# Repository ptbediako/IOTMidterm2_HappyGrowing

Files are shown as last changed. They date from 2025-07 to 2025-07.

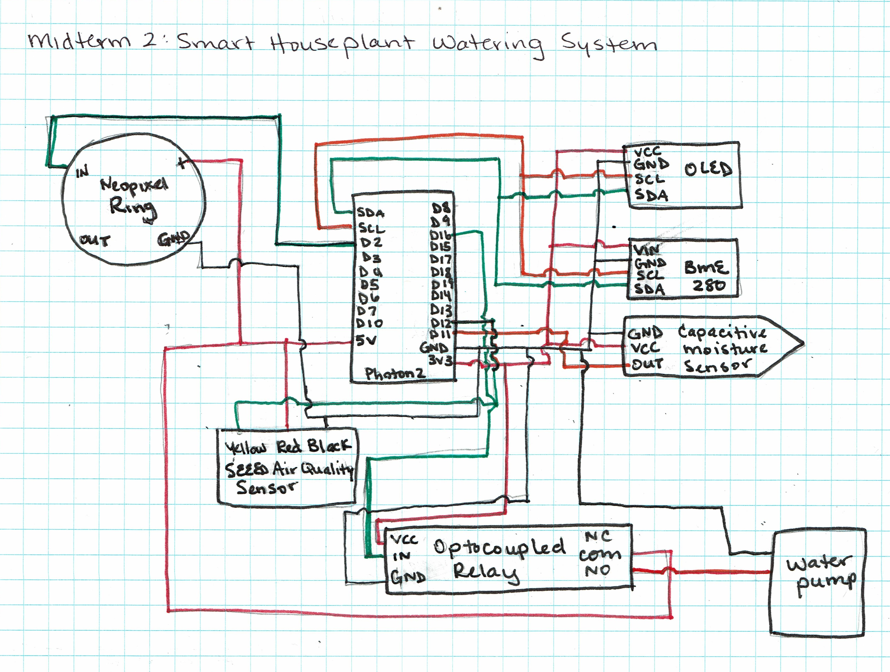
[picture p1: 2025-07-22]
Midterm2 Schematic_20250721cropped.jpg

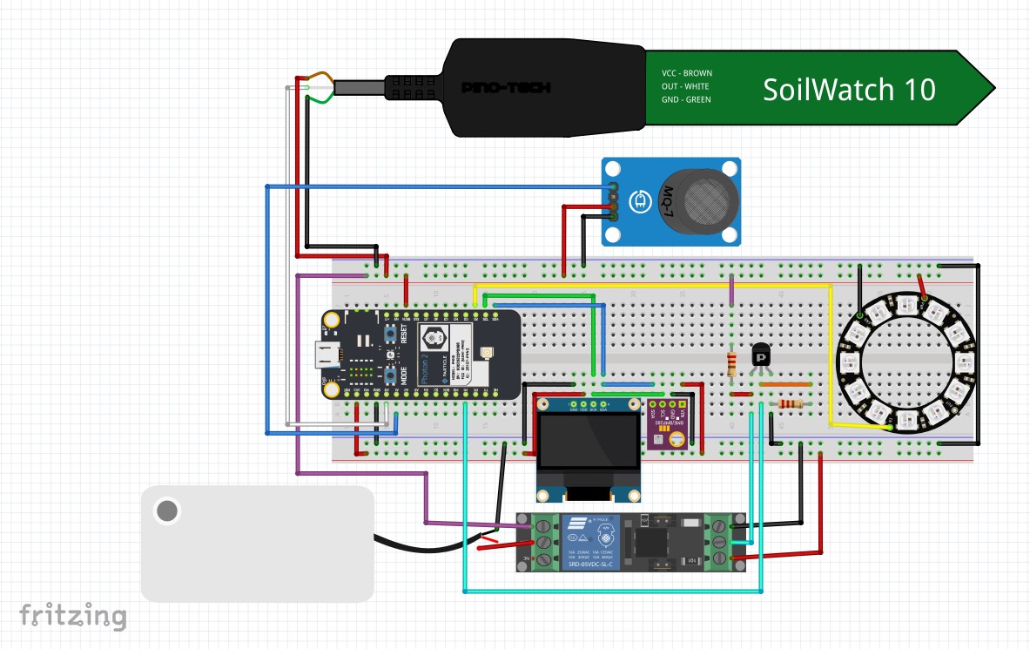
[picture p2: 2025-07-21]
Midterm2Fritzing_Screenshot.jpg

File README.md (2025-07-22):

# IoT Midterm 2 Happy Growing Smart Plant Care System
### Authored by Phylicia Bediako
### Hackster: 
[https://www.hackster.io/projects/b4e59b/edit#attachments](https://www.hackster.io/ptbediako/hg-smart-plant-care-system-b4e59b)

## Happy Growing: Intro and Motivation
The Happy Growing Smart Plant Care System helps simplify and automate plant care with environmental and soil sensors as well as hands-off watering options. As someone who chronically struggles with plant care, I wanted to create a system that would help me better understand what my plants need. The Happy Growing device includes an OLED programmed with messages "from" my plant that clearly communicates its preferences. After listing my plant type and its ideal conditions, the OLED displays the current conditions followed by complaints when the temperature, humidity, or soil conditions aren't quite right. The Happy Growing system includes automatic and remote manual watering options as well as Zapier alerts that send email reminders when the plant needs to be watered.

## Main Components
* Particle Photon2
* Environmental sensor: BME280 for measuring temperature, humidity, air pressure
* Air quality sensor: SEEED Grove Air Quality Sensor provides readings on levels of volatile organic compounds in the air
* Soil sensor: Capacitive soil moisture sensor for measuring soil moisture/dryness
* Watering system: Water pump with octocoupled relay provides manual and automatic soil watering options
* Display: OLED for displaying temperature, humidity, air pressure, soil moisture, air quality
* Status lights: Neopixels for displaying whether room and soil conditions are within bounds
  
## Parts
* Flower pot (3D printed)
* Platform with flower pot holder and water resevoir (3D printed)
* Console case (3D printed)

## Equipment
* Bambu Lab X1 Carbon 3D Printer
* Bambu Lab A1 Mini 3D Printer
  
## Software
* C/C++ in Visual Studio Code
* SolidWorks
* Bambu Studio
  
## Features
* Dynamic OLED display message for communicating ideal conditions for specific plants as well as current conditions
* Plain-English indicator messages when your plant's needs are not being met
* Easy-to-see control panel lights showing when your plant might be unhappy
* Automatic and manual watering options with a plant stats dashboard and virtual watering button on Adafruit
* Zapier-Adafruit integrations that send an email when the plant needs to be watered

## How it works and what it does
The system relies on a BME280 and SEEED Grove Air Quality Sensor to measure environmental conditions as well as a capacitive soil moisture sensor to keep track of when the plant needs to be watered. The device includes an automatic mode that waters the plant when the soil reaches a minimum level of moisture and a manual but remote method for watering the plant via an Adafruit dashboard. To the right of the panel, a NeoPixel ring helps illuminate a happy and sad face to help you see if your plant is okay at a glance. The sad face shows when any of the environmental or soil conditions are off, while the happy face lights up when your plant is satisfied.

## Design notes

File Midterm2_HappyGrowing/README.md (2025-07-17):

# Midterm2_HappyGrowing

This firmware project was created using [Particle Developer Tools](https://www.particle.io/developer-tools/) and is compatible with all [Particle Devices](https://www.particle.io/devices/).

Feel free to replace this README.md file with your own content, or keep it for reference.

## Table of Contents
- [Introduction](#introduction)
- [Prerequisites To Use This Template](#prerequisites-to-use-this-repository)
- [Getting Started](#getting-started)
- [Particle Firmware At A Glance](#particle-firmware-at-a-glance)
  - [Logging](#logging)
  - [Setup and Loop](#setup-and-loop)
  - [Delays and Timing](#delays-and-timing)
  - [Testing and Debugging](#testing-and-debugging)
  - [GitHub Actions (CI/CD)](#github-actions-cicd)
  - [OTA](#ota)
- [Support and Feedback](#support-and-feedback)
- [Version](#version)

## Introduction

For an in-depth understanding of this project template, please refer to our [documentation](https://docs.particle.io/firmware/best-practices/firmware-template/).

## Prerequisites To Use This Repository

To use this software/firmware on a device, you'll need:

- A [Particle Device](https://www.particle.io/devices/).
- Windows/Mac/Linux for building the software and flashing it to a device.
- [Particle Development Tools](https://docs.particle.io/getting-started/developer-tools/developer-tools/) installed and set up on your computer.
- Optionally, a nice cup of tea (and perhaps a biscuit).

## Getting Started

1. While not essential, we recommend running the [device setup process](https://setup.particle.io/) on your Particle device first. This ensures your device's firmware is up-to-date and you have a solid baseline to start from.

2. If you haven't already, open this project in Visual Studio Code (File -> Open Folder). Then [compile and flash](https://docs.particle.io/getting-started/developer-tools/workbench/#cloud-build-and-flash) your device. Ensure your device's USB port is connected to your computer.

3. Verify the device's operation by monitoring its logging output:
    - In Visual Studio Code with the Particle Plugin, open the [command palette](https://docs.particle.io/getting-started/developer-tools/workbench/#particle-commands) and choose "Particle: Serial Monitor".
    - Or, using the Particle CLI, execute:
    ```
    particle serial monitor --follow
    ```

4. Uncomment the code at the bottom of the cpp file in your src directory to publish to the Particle Cloud! Login to console.particle.io to view your devices events in real time.

5. Customize this project! For firmware details, see [Particle firmware](https://docs.particle.io/reference/device-os/api/introduction/getting-started/). For information on the project's directory structure, visit [this link](https://docs.particle.io/firmware/best-practices/firmware-template/#project-overview).

## Particle Firmware At A Glance

### Logging

The firmware includes a [logging library](https://docs.particle.io/reference/device-os/api/logging/logger-class/). You can display messages at different levels and filter them:

```
Log.trace("This is trace message");
Log.info("This is info message");
Log.warn("This is warn message");
Log.error("This is error message");
```

### Setup and Loop

Particle projects originate from the Wiring/Processing framework, which is based on C++. Typically, one-time setup functions are placed in `setup()`, and the main application runs from the `loop()` function.

For advanced scenarios, explore our [threading support](https://docs.particle.io/firmware/software-design/threading-explainer/).

### Delays and Timing

By default, the setup() and loop() functions are blocking whilst they run, meaning that if you put in a delay, your entire application will wait for that delay to finish before anything else can run. 

For techniques that allow you to run multiple tasks in parallel without creating threads, checkout the code example [here](https://docs.particle.io/firmware/best-practices/firmware-template/).

(Note: Although using `delay()` isn't recommended for best practices, it's acceptable for testing.)

### Testing and Debugging

For firmware testing and debugging guidance, check [this documentation](https://docs.particle.io/troubleshooting/guides/build-tools-troubleshooting/debugging-firmware-builds/).

### GitHub Actions (CI/CD)

This project provides a YAML file for GitHub, automating firmware compilation whenever changes are pushed. More details on [Particle GitHub Actions](https://docs.particle.io/firmware/best-practices/github-actions/) are available.

### OTA

To learn how to utilize Particle's OTA service for device updates, consult [this documentation](https://docs.particle.io/getting-started/cloud/ota-updates/).

Test OTA with the 'Particle: Cloud Flash' command in Visual Studio Code or the CLI command 'particle flash'!

This firmware supports binary assets in OTA packages, allowing the inclusion of audio, images, configurations, and external microcontroller firmware. More details are [here](https://docs.particle.io/reference/device-os/api/asset-ota/asset-ota/).

## Support and Feedback

For support or feedback on this template or any Particle products, please join our [community](https://community.particle.io)!

## Version

Template version 1.0.2

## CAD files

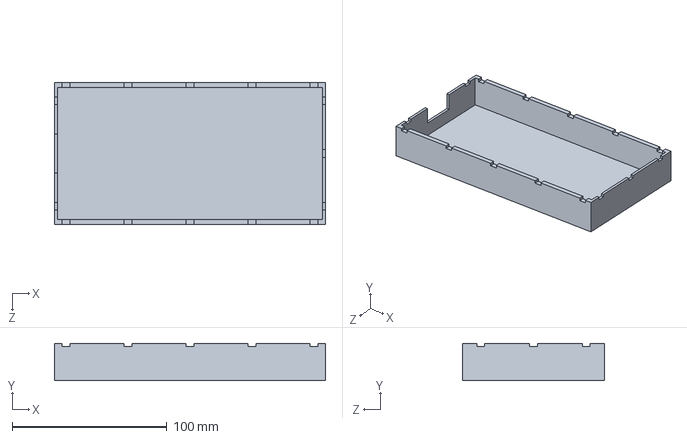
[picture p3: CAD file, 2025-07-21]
Midterm2SolidWorks/HG Breadboard Case Body.SLDPRT
175.0 x 24.0 x 92.0 mm

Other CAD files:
Midterm2SolidWorks/HG Breadboard Case Body.STL

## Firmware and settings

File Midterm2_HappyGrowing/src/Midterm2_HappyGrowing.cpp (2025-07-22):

/* 
 * Project myProject
 * Author: Your Name
 * Date: 
 * For comprehensive documentation and examples, please visit:
 * https://docs.particle.io/firmware/best-practices/firmware-template/
 */

// Include Particle Device OS APIs
#include "Particle.h"
#include "Adafruit_GFX.h"
#include "Adafruit_SSD1306.h"
#include "Adafruit_BME280.h"
#include "Adafruit_MQTT.h"
#include "Adafruit_MQTT/Adafruit_MQTT_SPARK.h"
#include "Adafruit_MQTT/Adafruit_MQTT.h"
#include "Air_Quality_Sensor.h" //Library name: Grove_Air_quality_Sensor
#include "Button.h"
#include "Colors.h"
#include "IoTTimer.h"
#include "neopixel.h"
#include "credentials.h"
#include "JsonParserGeneratorRK.h"
// #include "../lib/Adafruit_MQTT/src/Adafruit_MQTT.h"
// #include "../lib/Adafruit_MQTT/src/Adafruit_MQTT_SPARK.h"
// #include "../lib/Grove_Air_quality_Sensor/src/Air_Quality_Sensor.h"
// #include "../lib/Adafruit_BME280/src/Adafruit_BME280.h"
// #include "../lib/Adafruit_SSD1306/src/Adafruit_SSD1306.h"
// #include "../lib/neopixel/src/neopixel.h"

//Subscribe & Publish
TCPClient TheClient;
Adafruit_MQTT_SPARK mqtt(&TheClient,AIO_SERVER,AIO_SERVERPORT,AIO_USERNAME,AIO_KEY);  
Adafruit_MQTT_Publish hgSoilFeed = Adafruit_MQTT_Publish(&mqtt, AIO_USERNAME "/feeds/HGSoilFeed");
Adafruit_MQTT_Publish hgAirFeed = Adafruit_MQTT_Publish(&mqtt, AIO_USERNAME "/feeds/HGAirQualFeed");
Adafruit_MQTT_Publish hgTempFeed = Adafruit_MQTT_Publish(&mqtt, AIO_USERNAME "/feeds/HGTempFeed");
Adafruit_MQTT_Publish hgHumidFeed = Adafruit_MQTT_Publish(&mqtt, AIO_USERNAME "/feeds/HGHumidityFeed");
Adafruit_MQTT_Publish hgPressFeed = Adafruit_MQTT_Publish(&mqtt, AIO_USERNAME "/feeds/HGAirPressureFeed");
//Adafruit_MQTT_Subscribe subFeed = Adafruit_MQTT_Subscribe(&mqtt, AIO_USERNAME "/feeds/buttononoff");
Adafruit_MQTT_Subscribe hgButtonSub = Adafruit_MQTT_Subscribe(&mqtt, AIO_USERNAME "/feeds/hgbuttonsub");

float pubValue;
int hgButtonPress; //replaced subValue
void MQTT_connect();
bool MQTT_ping();
unsigned int lastPubTime;

//Soil Moisture Sensor Variables
int soilDryness;
const int SOILPIN=A0;

//SEEED Air Quality Sensor Variables
const int AIRQUALPIN=A1;
int airQuality;
AirQualitySensor sensor(AIRQUALPIN);

//BME Variables
float tempC, tempF, humidRH, pressPA, pressInHg;
const char DEGREE=0xF8;
const char PCT=0x25;
const int BME280=0x76;
bool status;
Adafruit_BME280 bme;
bool tempProblem, humidProblem, soilProblem;

//OLED Variables
const int OLEDSCRN=0x3c;
const int OLED_RESET = -1;
Adafruit_SSD1306 display(OLED_RESET);
int displayMode;
unsigned int lastDisplayTime;

//Neopixel variables
const int PIXELCOUNT=12;
int pix;
int startPixel, endPixel, color;
Adafruit_NeoPixel pixel (PIXELCOUNT,SPI1,WS2812B);
void pixelFill(int startPixel, int endPixel, int color);

//Water Pump
const int WATERPIN=D16;
int waterTimer, lastWaterTimer;

//Timestamp variables
String dateTime;
String timeHHMM; //formatted time var
String dateMMDD; //formatted date var
const int MDTTIME = -6;
const int MSTTIME = -7;
unsigned int lastTime;

SYSTEM_MODE(AUTOMATIC);

void displayMessage(int textSize, char message[]);


void setup() {
  Wire.begin();
  Serial.begin(9600);
  waitFor(Serial.isConnected,10000);
  
  WiFi.on();
  WiFi.connect();
  while(WiFi.connecting()) {
    Serial.printf(".");
  }
  Serial.printf("\n\n");

  mqtt.subscribe(&hgButtonSub);
  
  Time.zone(MDTTIME);
  Particle.syncTime();

   status = bme.begin(BME280);
   if (status == false){
     Serial.printf("BME280 at address 0x%02x failed to start",BME280);
   }

   display.begin(SSD1306_SWITCHCAPVCC,OLEDSCRN);
   display.setTextColor(WHITE);
   display.display();
   display.clearDisplay();


   pixel.begin();
   pixel.setBrightness(35);
   pixel.show();

   Serial.printf("Waiting for sensor to intitialize...");
   delay(20000);

   if(sensor.init()){
     Serial.printf("Sensor ready.");
   }
   else{
     Serial.printf("Sensor ERROR");
   }

  pinMode(WATERPIN,OUTPUT);
}

/***************************************************************/
void loop() {
  MQTT_connect();
  MQTT_ping();

  dateTime= Time.timeStr(); //current date and time
  timeHHMM = dateTime.substring(11,16); //for time that displays only hours and mins (no seconds)
  dateMMDD= dateTime.substring(4,9); //for date that displays only month and day (no day of week or year)
  soilDryness = analogRead(SOILPIN);
  airQuality=sensor.slope();

   tempC=bme.readTemperature();
   tempF=(tempC*1.8)+32;
   humidRH=bme.readHumidity();
   pressPA= bme.readPressure();
   pressInHg=(pressPA * 0.0002952998751);

   if((soilDryness>=1700)&&(soilDryness<=2500)){
    soilProblem=0;
   }
    if((soilDryness>2500)){
      soilProblem=1;
      }
    if((soilDryness<1700)){
      soilProblem=1;
    }

  if((humidRH>=50)&&(humidRH<=70)){
    humidProblem=0;
  }
  if ((humidRH <50)){
    humidProblem=1;
  }
  if ((humidRH >70)){
    humidProblem=1;
  }

  if((tempF>=65) &&(tempF<=85)){
    tempProblem=0;
  }
  if ((tempF>85)){     
    tempProblem=1;
  }
  if ((tempF<65)){ 
    tempProblem=1;
  }
  Serial.printf("T %i, H %i, S %i", tempProblem, humidProblem, soilProblem);

  
  Adafruit_MQTT_Subscribe *subscription;
  while ((subscription = mqtt.readSubscription(100))) {
    if (subscription == &hgButtonSub) {
      hgButtonPress = atoi((char *)hgButtonSub.lastread);

       if(hgButtonPress==1){
        digitalWrite(WATERPIN,HIGH);
       }
       if(hgButtonPress==0){
        digitalWrite(WATERPIN,LOW);
       }
     }
      Serial.printf("HG Water Button %i\n",hgButtonPress);
  }

  if((millis()-lastPubTime)>30000){
    if(mqtt.Update()){
      hgSoilFeed.publish(soilDryness,1);
      hgAirFeed.publish(airQuality,1);
      hgTempFeed.publish(tempF,1);
      hgHumidFeed.publish(humidRH,1);
      hgPressFeed.publish(pressInHg,1);
    }
    lastPubTime = millis();
  }

  


//Displays
 if ((millis()-lastDisplayTime)>4000){
  displayMode++;
  if(displayMode==6){
    displayMode=1;
  }
   lastDisplayTime = millis();
 }

//Screen 1: Intro
  if ((displayMode==1)){
    display.clearDisplay();
    display.setCursor(0,0);
    display.setTextSize(1);
    display.printf("Hi! I'm a\nRED BANANA CROTON\n \nI like\nTemp: 65-85%cF\nHumidity: 50-70%cRH\nWater every 3-5 days",DEGREE,PCT);
    display.display();
  }

//Screen 2: Current Conditions
  if((displayMode==2)){
    display.setTextSize(1);
    display.setCursor(0,0);
    display.clearDisplay();
    display.printf("%s at %s\nTemp: %0.1f %cF\nHumidity: %0.1f %cRH\nSoil Dryness: %i\nAirQuality: %i\nPressure: %0.1f inHG",dateMMDD.c_str(), timeHHMM.c_str(), tempF, DEGREE, humidRH, PCT, soilDryness,airQuality, pressInHg);
    display.display();
  }

//Screen 3: Temperature Problems
  if((displayMode==3)){ 
    if ((tempF>85)){     
      displayMessage(2,"I'm hot!");
    }
    if ((tempF<65)){ 
      displayMessage(2,"I'm cold!");
    }
  }

//Screen 4: Humidity Problems
  if((displayMode==4)){
    if ((humidRH <50)){
      displayMessage(2, "The air is\ntoo dry!");
    }
    if ((humidRH >70)){
      displayMessage(2, "It's too\nhumid!");
    }
  }

//Screen 5: Soil Watering Problems
  if((displayMode==5)){
    if((soilDryness>2500)){
      displayMessage(2, "The soil\nis too\ndry!");
      }

    if((soilDryness<1700)){
      displayMessage(2, "I'm\ndrowning!");
    }
  }  

  //Watering the Soil
  waterTimer=millis();

  if((soilDryness>2500)){
    if((waterTimer-lastWaterTimer)>60000){
      digitalWrite(WATERPIN,HIGH);
    }
    if((waterTimer-lastWaterTimer)>61000){
      lastWaterTimer=waterTimer;
      digitalWrite(WATERPIN,LOW);
    }
  }

//NeoPixels
  if ((tempProblem == 0) && (humidProblem ==0) && (soilProblem == 0)){
    startPixel=0;
    endPixel= 5;
    pixelFill(startPixel, endPixel, green);

    startPixel=6;
    endPixel= 11;
    pixelFill(startPixel, endPixel, 0x000000);
  }
  if ((tempProblem == 1) || (humidProblem ==1) || (soilProblem == 1)){
    startPixel=6;
    endPixel= 11;
    pixelFill(startPixel, endPixel, red);

    startPixel=0;
    endPixel= 5;
    pixelFill(startPixel, endPixel, 0x000000);
  }

  //Air Quality
  Serial.printf("(Sensor value: %i)\n",airQuality);
  if (airQuality == AirQualitySensor::FORCE_SIGNAL){
    Serial.printf("Warning! Excessive pollution!");
    }
  if (airQuality == AirQualitySensor::HIGH_POLLUTION) {
    Serial.printf("High pollution ");
  }
  if (airQuality == AirQualitySensor::LOW_POLLUTION) {
    Serial.printf("Low pollution ");
  }
  if (airQuality == AirQualitySensor::FRESH_AIR) {
    Serial.printf("Fresh air ");  
  }

}

/************************************************************/
void displayMessage(int textSize, char message[]){
  display.setTextSize(textSize);
  display.setTextColor(WHITE);
  display.setCursor(0, 0);
  display.clearDisplay();
  display.printf(message);
  display.display();
}

/************************************************************/
void pixelFill(int startPixel, int endPixel, int color){
  for(pix=startPixel; pix<=endPixel; pix=pix+1){
    pixel.setPixelColor(pix, color);
  }
  pixel.show();
  delay(100);
}

/************************************************************/
void MQTT_connect() {
  int8_t ret;
 
  // Return if already connected.
  if (mqtt.connected()) {
    return;
  }
 
  Serial.print("Connecting to MQTT... ");
 
  while ((ret = mqtt.connect()) != 0) { // connect will return 0 for connected
       Serial.printf("Error Code %s\n",mqtt.connectErrorString(ret));
       Serial.printf("Retrying MQTT connection in 5 seconds...\n");
       mqtt.disconnect();
       delay(5000);  // wait 5 seconds and try again
  }
  Serial.printf("MQTT Connected!\n");
}

/************************************************************/
bool MQTT_ping() {
  static unsigned int last;
  bool pingStatus;

  if ((millis()-last)>120000) {
      Serial.printf("Pinging MQTT \n");
      pingStatus = mqtt.ping();
      if(!pingStatus) {
        Serial.printf("Disconnecting \n");
        mqtt.disconnect();
      }
      last = millis();
  }
  return pingStatus;
}

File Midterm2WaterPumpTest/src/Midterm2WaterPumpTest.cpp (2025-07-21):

/* 
 * Project myProject
 * Author: Your Name
 * Date: 
 * For comprehensive documentation and examples, please visit:
 * https://docs.particle.io/firmware/best-practices/firmware-template/
 */
/*
// Include Particle Device OS APIs
#include "Particle.h"

const int WATERPIN=D16;

// Let Device OS manage the connection to the Particle Cloud
SYSTEM_MODE(SEMI_AUTOMATIC);


void setup() {
  Serial.begin(9600);
  waitFor(Serial.isConnected, 10000);

  digitalWrite(WATERPIN,LOW);
  pinMode(WATERPIN,OUTPUT);
}


void loop() {
  digitalWrite(WATERPIN,HIGH);
  delay(750);

  digitalWrite(WATERPIN,LOW);
  delay(10000);
}
*/

#include "Particle.h"
#include <Adafruit_MQTT.h>
#include "Adafruit_MQTT/Adafruit_MQTT_SPARK.h"
#include "Adafruit_MQTT/Adafruit_MQTT.h"
#include "credentials.h"
#include "button.h"

/************ Global State (you don't need to change this!) ***   ***************/ 
TCPClient TheClient; 

// Setup the MQTT client class by passing in the WiFi client and MQTT server and login details. 
Adafruit_MQTT_SPARK mqtt(&TheClient,AIO_SERVER,AIO_SERVERPORT,AIO_USERNAME,AIO_KEY); 

/****************************** Feeds ***************************************/ 
// Setup Feeds to publish or subscribe 
// Notice MQTT paths for AIO follow the form: <username>/feeds/<feedname> 
//Adafruit_MQTT_Subscribe subFeed = Adafruit_MQTT_Subscribe(&mqtt, AIO_USERNAME "/feeds/buttononoff"); 
Adafruit_MQTT_Subscribe subFeed = Adafruit_MQTT_Subscribe(&mqtt, AIO_USERNAME "/feeds/midterm2hgwaterbutton");
Adafruit_MQTT_Publish pubFeed = Adafruit_MQTT_Publish(&mqtt, AIO_USERNAME "/feeds/L09_01_SubscribePublish");

/************Declare Variables*************/
unsigned int last, lastTime;
float pubValue;
int subValue;
const int BLULED=D16;


/************Declare Functions*************/
void MQTT_connect();
bool MQTT_ping();


SYSTEM_MODE(SEMI_AUTOMATIC);

void setup() {
  Serial.begin(9600);
  waitFor(Serial.isConnected,10000);

  // Connect to Internet but not Particle Cloud
  WiFi.on();
  WiFi.connect();
  while(WiFi.connecting()) {
    Serial.printf(".");
  }
  Serial.printf("\n\n");

  // Setup MQTT subscription
  mqtt.subscribe(&subFeed);

  pinMode(BLULED,OUTPUT);
}

void loop() {
  MQTT_connect();
  MQTT_ping();

  // this is our 'wait for incoming subscription packets' busy subloop 
  Adafruit_MQTT_Subscribe *subscription;
  while ((subscription = mqtt.readSubscription(100))) {
    if (subscription == &subFeed) {
      subValue = atoi((char *)subFeed.lastread);
      
            
      if(subValue==1){
      digitalWrite(BLULED,HIGH);
      }
      else{
      digitalWrite(BLULED,LOW);
      }
    }
      Serial.printf("Button %i\n",subValue);
    }
  


  if((millis()-lastTime > 6000)) {
    if(mqtt.Update()) {
      pubValue=random(300.0);
      pubFeed.publish(pubValue);
      Serial.printf("Publishing %0.2f \n",pubValue); 
      } 
    lastTime = millis();
  }
}

// Function to connect and reconnect as necessary to the MQTT server.
// Should be called in the loop function and it will take care if connecting.
void MQTT_connect() {
  int8_t ret;
 
  // Return if already connected.
  if (mqtt.connected()) {
    return;
  }
 
  Serial.print("Connecting to MQTT... ");
 
  while ((ret = mqtt.connect()) != 0) { // connect will return 0 for connected
       Serial.printf("Error Code %s\n",mqtt.connectErrorString(ret));
       Serial.printf("Retrying MQTT connection in 5 seconds...\n");
       mqtt.disconnect();
       delay(5000);  // wait 5 seconds and try again
  }
  Serial.printf("MQTT Connected!\n");
}


bool MQTT_ping() {
  static unsigned int last;
  bool pingStatus;

  if ((millis()-last)>120000) {
      Serial.printf("Pinging MQTT \n");
      pingStatus = mqtt.ping();
      if(!pingStatus) {
        Serial.printf("Disconnecting \n");
        mqtt.disconnect();
      }
      last = millis();
  }
  return pingStatus;
}

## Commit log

2025-07-21 Midterm 2 Files
    [HG Breadboard Case Body.SLDPRT, HG Breadboard Case Body.STL, Midterm2Fritzing.fzz]
2025-07-21 Midterm 2 code added
    [Midterm2Fritzing.fzz]
